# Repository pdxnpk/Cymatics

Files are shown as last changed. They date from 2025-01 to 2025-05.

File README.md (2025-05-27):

# Cymatics

Integrated PCBs for AudioLux and Vibrosonics

# Development

Install KiCad (version 8.0 or higher): https://www.kicad.org/download/

Open KiCad project file (Cymatics/Cymatics.kicad_pro)

# Build a PCB

## Order PCB

Go to JLCPCB (https://jlcpcb.com/) or PCBWay (https://www.pcbway.com/) to order a PCB

Start an order for a 2-layer PCB (Standard)

Add zip file of Gerber and Drill files (Fabrication/Cymatics_Gerber_Drill_03-21-25.zip)

Default specifications and options are OK

## Parts and Assembly

You may choose to have the PCB manufacturer assemble the boards for you, or you may order the parts separately and assemble the board on your own.

### Order PCB assembly

Provide the BOM and CPL (component placement list, or Centroid) for the manufacturer when requesting PCB assembly.

- Fabrication/Fabrication-BOM.xlsx: BOM adhering to PCBWay format (may need to revise for other manufacturers)

- Fabrication/Fabrication-CPL.csv: CPL or Centroid

### Order components separately

Open shopping list (Shopping-List.csv) to find links to order parts

Go to DigiKey (https://www.digikey.com/) and order listed part quanities

# Program the Microcontroller

To program the ESP32 with AudioLux and/or VibroSonics software, refer to their respective GitHub repositories.

- AudioLux software: https://github.com/OPEnSLab-OSU/Nanolux

- VibroSonics software: https://github.com/udellc/Vibrosonics

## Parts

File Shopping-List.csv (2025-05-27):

Reference | Footprint | Value | Order Link (Datasheet) | Qty | Price per unit |  | Notes
U1 | D14 | SN74AHCT125DR | https://www.digikey.com/en/products/detail/texas-instruments/SN74AHCT125DR/376412 | 1 | 0.26 | 0.26
J18 | TerminalBlock_TE-Connectivity:TerminalBlock_TE_282834-6_1x06_P2.54mm_Horizontal | Screw_Terminal_01x06 | https://www.digikey.com/en/products/detail/te-connectivity-amp-connectors/282834-6/1153267 | 1 | 8.84 | 8.84
J11 | TerminalBlock_TE-Connectivity:TerminalBlock_TE_282834-5_1x05_P2.54mm_Horizontal | Screw_Terminal_01x05 | https://www.digikey.com/en/products/detail/te-connectivity-amp-connectors/282834-5/1153266 | 1 | 6.2 | 6.2
J8,J10 | TerminalBlock_TE-Connectivity:TerminalBlock_TE_282834-4_1x04_P2.54mm_Horizontal | Screw_Terminal_01x04 | https://www.digikey.com/en/products/detail/te-connectivity-amp-connectors/282834-4/1153265 | 2 | 5.08 | 10.16
J1,J3,J4,J16 | TerminalBlock_TE-Connectivity:TerminalBlock_TE_282834-3_1x03_P2.54mm_Horizontal | Screw_Terminal_01x03 | https://www.digikey.com/en/products/detail/te-connectivity-amp-connectors/282834-3/1153264 | 4 | 3.93 | 15.72
J2,J5,J9,J12,J13,J15,J17 | TerminalBlock_TE-Connectivity:TerminalBlock_TE_282834-2_1x02_P2.54mm_Horizontal | Screw_Terminal_01x02 | https://www.digikey.com/en/products/detail/te-connectivity-amp-connectors/282834-2/1150135 | 7 | 2.74 | 19.18
J14,J19,J20,J21,J22,J23,J24 | CONN1_RCU-0C_TEC | RCU-0C | https://www.digikey.com/en/products/detail/te-connectivity-amp-connectors/RCU-0C/2366048 | 7 | 0.22 | 1.54
SD1 | MSD-4-A:CUI_MSD-4-A | MSD-4-A | https://www.digikey.com/en/products/detail/same-sky-formerly-cui-devices/MSD-4-A/21796808 | 1 | 0.36 | 0.36
U2 | 21-0041B_8_MXM | MAX7480ESA+ | https://www.digikey.com/en/products/detail/analog-devices-inc-maxim-integrated/max7480esa/1513397 | 1 | 9.24 | 9.24
IC2,IC5 | 21-0041B_8_MXM | MAX7403CSA+ | https://www.digikey.com/en/products/detail/analog-devices-inc-maxim-integrated/max7403csa/1513320 | 2 | 8.78 | 17.56
IC1,IC3,IC4 | D8 | LMV358IDR | https://www.digikey.com/en/products/detail/texas-instruments/LMV358IDR/381251 | 3 | 0.38 | 1.14
J6 | Connector_PinSocket_2.54mm:PinSocket_1x16_P2.54mm_Vertical | Conn_01x16_Socket | https://www.digikey.com/en/products/detail/sullins-connector-solutions/PPTC161LFBN-RC/810154 | 1 | 0.9 | 0.9
J7 | Connector_PinSocket_2.54mm:PinSocket_1x12_P2.54mm_Vertical | Conn_01x12_Socket | https://www.digikey.com/en/products/detail/sullins-connector-solutions/PPTC121LFBN-RC/807231 | 1 | 0.73 | 0.73
RN1,RN2 | CAY16-473:RESCAF80P320X160X60-8N | CAY16-473J4LF | https://www.digikey.com/en/products/detail/bourns-inc/CAY16-473J4LF/2566758 | 2 | 0.1 | 0.2
RN3 | CAY16-103:RESCAF80P320X160X60-8N | CAY16-103J4LF | https://www.digikey.com/en/products/detail/bourns-inc/CAY16-103J4LF/431579 | 1 | 0.1 | 0.1
R9,R22 | Resistor_SMD:R_1206_3216Metric | 22k | https://www.digikey.com/en/products/detail/yageo/RC1206FR-0722KL/728688 | 2 | 0.1 | 0.2
R1,R2,R3,R4,R7,R8,R12,R13,R16,R17,R20,R21,R24,R25 | Resistor_SMD:R_1206_3216Metric | 10k | https://www.digikey.com/en/products/detail/yageo/RC1206FR-0710KL/728483 | 14 | 0.1 | 1.4
R5 | Resistor_SMD:R_1206_3216Metric | 7.5k | https://www.digikey.com/en/products/detail/yageo/RC1206FR-077K5L/729079 | 1 | 0.1 | 0.1
R10,R23 | Resistor_SMD:R_1206_3216Metric | 6.2k | https://www.digikey.com/en/products/detail/yageo/RC1206FR-076K2L/729016 | 2 | 0.1 | 0.2
R6 | Resistor_SMD:R_1206_3216Metric | 5k | https://www.digikey.com/en/products/detail/yageo/RT1206BRD075KL/5936961 | 1 | 0.32 | 0.32
R19,R26 | Resistor_SMD:R_1206_3216Metric | 3.3k | https://www.digikey.com/en/products/detail/yageo/RC1206FR-073K3L/728766 | 2 | 0.1 | 0.2
R15,R18 | Resistor_SMD:R_1206_3216Metric | 1.5k | https://www.digikey.com/en/products/detail/yageo/RC1206FR-071K5L/728441 | 2 | 0.1 | 0.2
R11,R14 | Resistor_SMD:R_1206_3216Metric | 150 | https://www.digikey.com/en/products/detail/yageo/RC1206JR-07150RL/729223 | 2 | 0.1 | 0.2
C17 | Capacitor_THT:CP_Radial_D8.0mm_P5.00mm | 1000uF | https://www.digikey.com/en/products/detail/rubycon/10ZLH1000MEFC10X12-5/3134015 | 1 | 0.54 | 0.54
C1,C2,C6,C7,C8,C10,C11,C15,C20,C21,C22,C23 | Capacitor_SMD:C_0805_2012Metric | 10uF | https://www.digikey.com/en/products/detail/yageo/CC0805ZKY5V6BB106/2103093 | 12 | 0.15 | 1.8
C3,C4,C9,C12,C13,C16,C18,C24,C25 | Capacitor_SMD:C_0805_2012Metric | 0.1uF | https://www.digikey.com/en/products/detail/yageo/CC0805KRX7R9BB104/302874 | 9 | 0.08 | 0.72
C19 | Capacitor_SMD:C_0805_2012Metric | 6.8nF | https://www.digikey.com/en/products/detail/yageo/CC0805KRX7R9BB682/302869 | 1 | 0.1 | 0.1
C5,C14 | Capacitor_SMD:C_0805_2012Metric | 100pF | https://www.digikey.com/en/products/detail/yageo/CC0805JRNPO9BN101/302845 | 2 | 0.1 | 0.2
 |  |  |  |  |  | 98.31 | Total cost of 1 Cymatics PCB
External Modules | Part Number |  | Order Link (Datasheet)
Stereo Pot 1k linear | PDB182-K220K-102B |  | https://www.digikey.com/en/products/detail/bourns-inc/PDB182-K220K-102B/2564758 | 1 | 2.18 | 2.18
Rotary Encoder | PEC11R-4215F-S0024 |  | https://www.digikey.com/en/products/detail/bourns-inc/PEC11R-4215F-S0024/4499665 | 1 | 2.2 | 2.2
Stereo Jack 3.5mm | 35PRM3 |  | https://www.digikey.com/en/products/detail/switchcraft-inc/35PRM3/6695851 | 1 | 2.16 | 2.16
Buck Converter | DFR1015 |  | https://www.digikey.com/en/products/detail/dfrobot/DFR1015/18069278 | 1 | 5.3 | 5.3
Red LED | C503B-RAN-CA0B0AA1 |  | https://www.digikey.com/en/products/detail/cree-led/C503B-RAN-CA0B0AA1/4793651 | 2 | 0.22 | 0.44
Pololu LED Strip | SK9822 |  | https://www.pololu.com/product/3086 | 1 | 25.7 | 25.7
Adafruit Amplifier Board | MAX9744 |  | https://www.adafruit.com/product/1752 | 1 | 19.95 | 19.95
Dayton Audio Transducer | TT25-8 |  | https://www.amazon.com/Dayton-Audio-TT25-8-Tactile-Transducer/dp/B009RGJ47S/ref=sr_1_1_pp?sr=8-1 | 3 | 17.34 | 52.02
 |  |  |  |  |  | 109.95 | Total cost of external modules for 1 system
 |  |  |  |  |  | 208.26 | Total cost of 1 system (PCB and external modules). May vary due to bulk pricing and shipping fees .

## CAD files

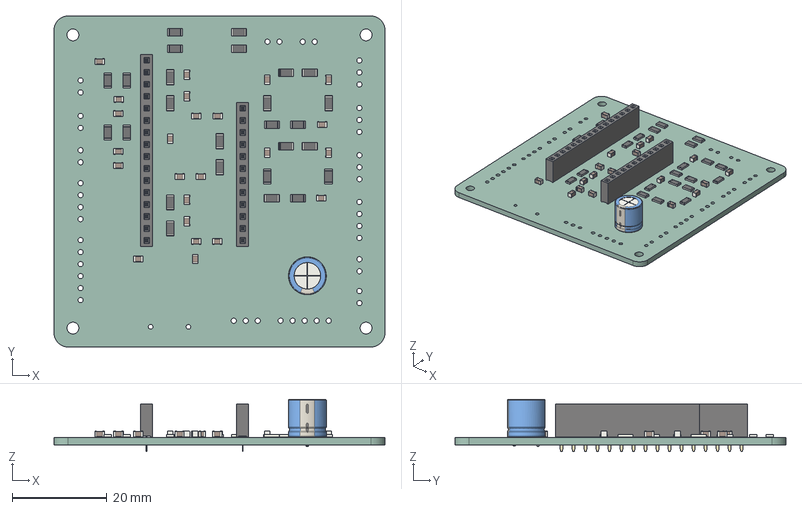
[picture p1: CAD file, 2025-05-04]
Cymatics/Cymatics.step
70.0 x 70.0 x 11.1 mm
R_1206_3216Metric x 26
C_0805_2012Metric x 24
PinSocket_1x12_P254mm_Vertical
CP_Radial_D80mm_P500mm
PinSocket_1x16_P254mm_Vertical
Cymatics_PCB

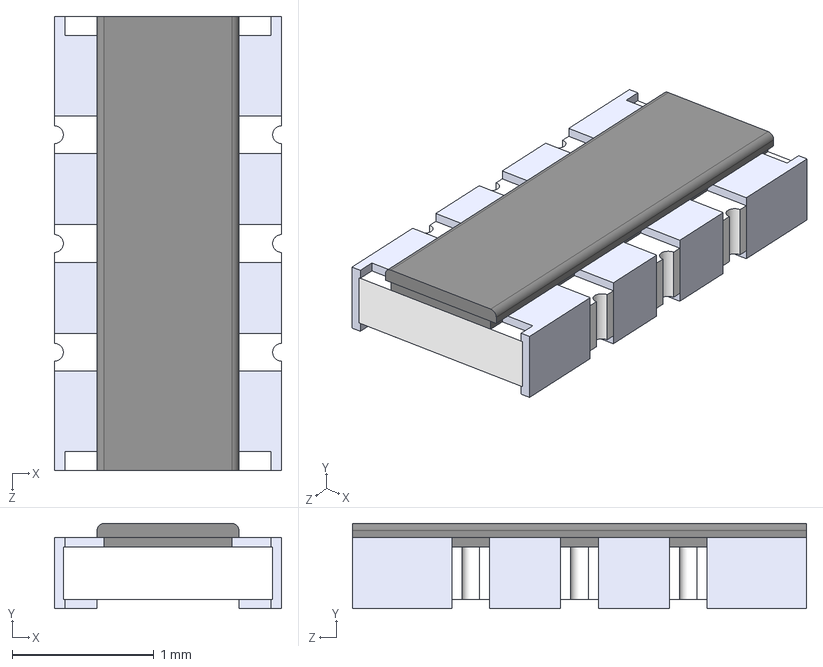
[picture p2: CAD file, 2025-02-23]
Cymatics/Footprints/CAY16_103J4LF/CAY16-103J4LF.step
1.60 x 0.6 x 3.20 mm

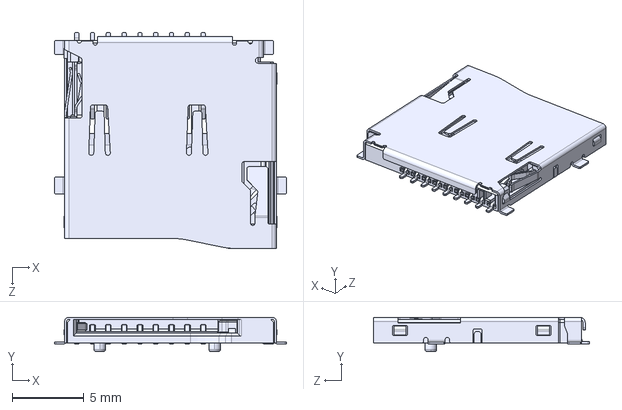
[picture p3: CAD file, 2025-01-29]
Cymatics/Footprints/MSD_4_A/MSD-4-A.step
16.1 x 2.40 x 15.0 mm

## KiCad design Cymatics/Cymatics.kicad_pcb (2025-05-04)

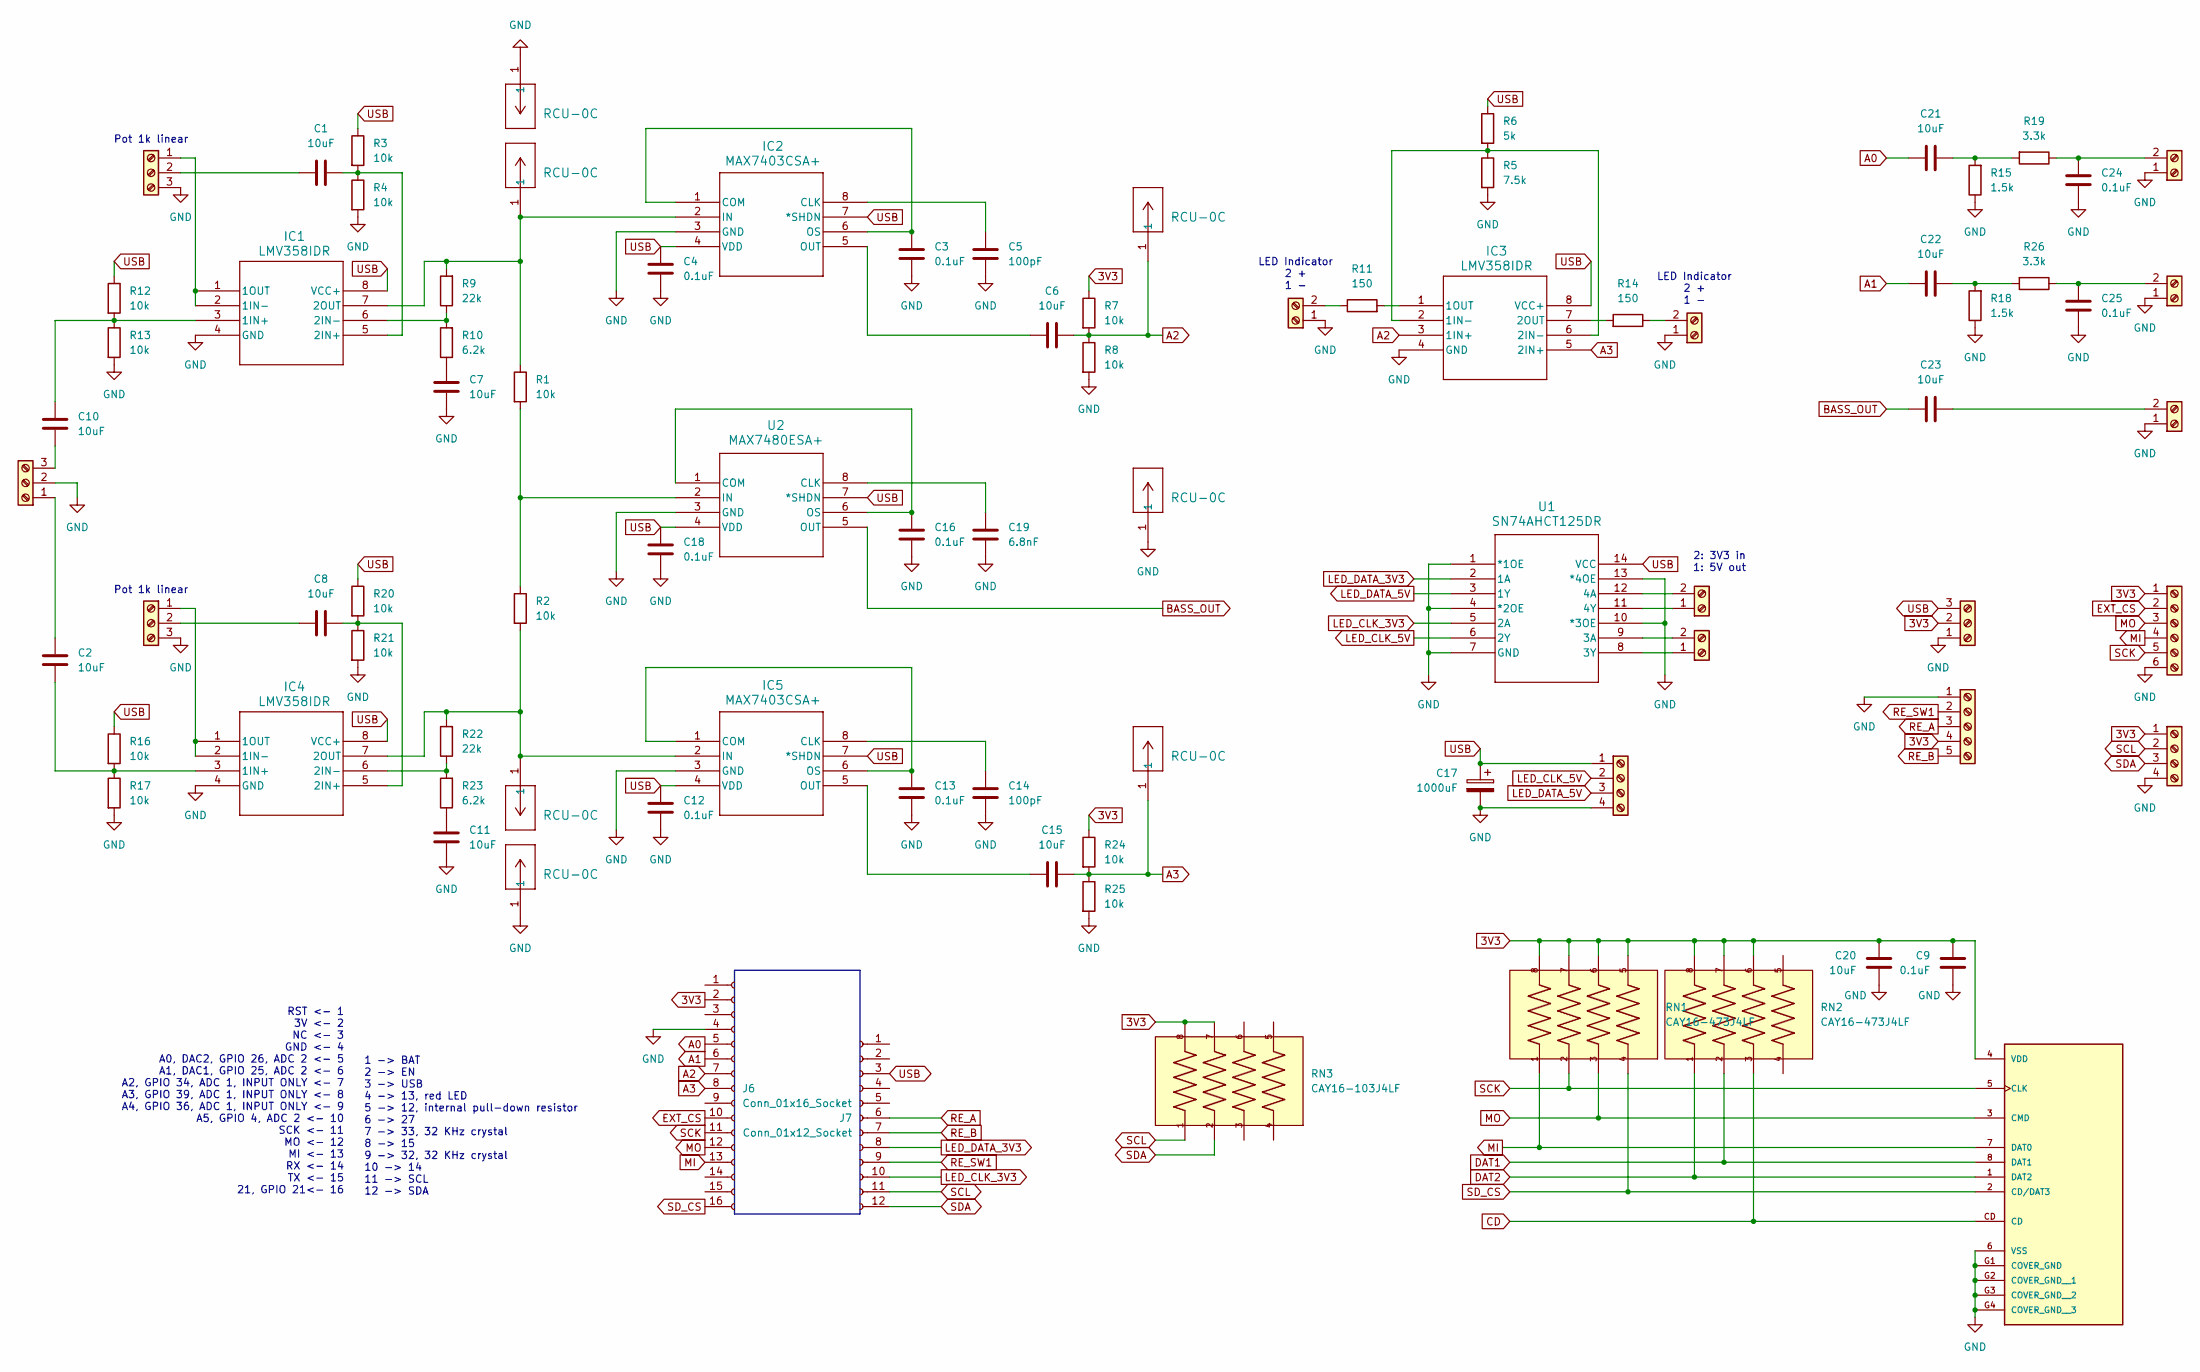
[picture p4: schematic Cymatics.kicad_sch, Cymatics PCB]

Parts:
C1, C2, C6, C7, C8, C10, C11, C15, C20, C21, C22, C23: 10uF; C_0805_2012Metric
C3, C4, C9, C12, C13, C16, C18, C24, C25: 0.1uF; C_0805_2012Metric
C5, C14: 100pF; C_0805_2012Metric
C17: 1000uF; CP_Radial_D8.0mm_P5.00mm
C19: 6.8nF; C_0805_2012Metric
IC1, IC3, IC4: LMV358IDR; D8
IC2, IC5: MAX7403CSA+; 21-0041B_8_MXM
J1, J3, J4, J16: Screw_Terminal_01x03; TerminalBlock_TE_282834-3_1x03_P2.54mm_Horizontal
J2, J5, J9, J12, J13, J15, J17: Screw_Terminal_01x02; TerminalBlock_TE_282834-2_1x02_P2.54mm_Horizontal
J6: Conn_01x16_Socket; PinSocket_1x16_P2.54mm_Vertical
J7: Conn_01x12_Socket; PinSocket_1x12_P2.54mm_Vertical
J8, J10: Screw_Terminal_01x04; TerminalBlock_TE_282834-4_1x04_P2.54mm_Horizontal
J11: Screw_Terminal_01x05; TerminalBlock_TE_282834-5_1x05_P2.54mm_Horizontal
J14, J19, J20, J21, J22, J23, J24: RCU-0C; CONN1_RCU-0C_TEC
J18: Screw_Terminal_01x06; TerminalBlock_TE_282834-6_1x06_P2.54mm_Horizontal
R1, R2, R3, R4, R7, R8, R12, R13, R16, R17, R20, R21, R24, R25: 10k; R_1206_3216Metric
R5: 7.5k; R_1206_3216Metric
R6: 5k; R_1206_3216Metric
R9, R22: 22k; R_1206_3216Metric
R10, R23: 6.2k; R_1206_3216Metric
R11, R14: 150; R_1206_3216Metric
R15, R18: 1.5k; R_1206_3216Metric
R19, R26: 3.3k; R_1206_3216Metric
RN1, RN2: CAY16-473J4LF; RESCAF80P320X160X60-8N
RN3: CAY16-103J4LF; RESCAF80P320X160X60-8N
SD1: MSD-4-A; CUI_MSD-4-A; PARTREV 1.0
U1: SN74AHCT125DR; D14
U2: MAX7480ESA+; 21-0041B_8_MXM

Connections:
3V3: C9.2, C20.1, J1.2, J6.2, J8.1, J11.4, J18.1, R7.1, R24.1, RN1.5, RN1.6, RN1.7, RN1.8, RN2.6, RN2.7, RN2.8, RN3.7, RN3.8, SD1.4 (VDD)
A0: C21.2, J6.5
A1: C22.2, J6.6
A2: C6.1, IC3.3 (1IN+), J6.7, J22.1, R7.2, R8.1
A3: C15.1, IC3.5 (2IN+), J6.8, J23.1, R24.2, R25.1
BASS_OUT: C23.2, U2.5 (OUT)
CD: RN2.3, SD1.CD
DAT1: RN2.2, SD1.8 (DAT1)
DAT2: RN2.1, SD1.1 (DAT2)
EXT_CS: J6.10, J18.2
GND: C3.1, C4.1, C5.1, C7.1, C9.1, C11.1, C12.1, C13.1, C14.1, C16.1, C17.2, C18.1, C19.1, C20.2, C24.1, C25.1, IC1.4 (GND), IC2.3 (GND), IC3.4 (GND), IC4.4 (GND), IC5.3 (GND), J1.1, J3.2, J4.3, J5.1, J6.4, J8.4, J10.4, J11.1, J12.1, J13.1, J15.1, J16.3, J17.1, J18.6, J19.1, J21.1, J24.1, R4.2, R5.2, R8.2, R13.2, R15.1, R17.2, R18.1, R21.2, R25.2, SD1.6 (VSS), SD1.G1 (COVER_GND), SD1.G2 (COVER_GND__1), SD1.G3 (COVER_GND__2), SD1.G4 (COVER_GND__3), U1.1 (*1OE), U1.4 (*2OE), U1.7 (GND), U1.10 (*3OE), U1.13 (*4OE), U2.3 (GND)
LED_CLK_3V3: J7.10, U1.5 (2A)
LED_CLK_5V: J10.2, U1.6 (2Y)
LED_DATA_3V3: J7.8, U1.2 (1A)
LED_DATA_5V: J10.3, U1.3 (1Y)
MI: J6.13, J18.4, RN1.1, SD1.7 (DAT0)
MO: J6.12, J18.3, RN1.3, SD1.3 (CMD)
unnamed: C7.2, R10.1
unnamed: C11.2, R23.1
unnamed: C21.1, R15.2, R19.2
unnamed: C22.1, R18.2, R26.2
unnamed: C10.1, IC1.3 (1IN+), R12.2, R13.1
unnamed: IC1.1 (1OUT), IC1.2 (1IN-), J4.1
unnamed: C1.1, IC1.5 (2IN+), R3.2, R4.1
unnamed: IC1.6 (2IN-), R9.1, R10.2
unnamed: IC1.7 (2OUT), IC2.2 (IN), J14.1, R1.1, R9.2
unnamed: C5.2, IC2.8 (CLK)
unnamed: C3.2, IC2.1 (COM), IC2.6 (OS)
unnamed: C6.2, IC2.5 (OUT)
unnamed: IC3.2 (1IN-), IC3.6 (2IN-), R5.1, R6.2
unnamed: IC3.1 (1OUT), R11.2
unnamed: IC3.7 (2OUT), R14.2
unnamed: C2.2, IC4.3 (1IN+), R16.2, R17.1
unnamed: IC4.1 (1OUT), IC4.2 (1IN-), J16.1
unnamed: C8.1, IC4.5 (2IN+), R20.2, R21.1
unnamed: IC4.6 (2IN-), R22.1, R23.2
unnamed: IC4.7 (2OUT), IC5.2 (IN), J20.1, R2.2, R22.2
unnamed: C14.2, IC5.8 (CLK)
unnamed: C13.2, IC5.1 (COM), IC5.6 (OS)
unnamed: C15.2, IC5.5 (OUT)
unnamed: J2.1, U1.11 (4Y)
unnamed: J2.2, U1.12 (4A)
unnamed: C2.1, J3.1
unnamed: C10.2, J3.3
unnamed: C1.2, J4.2
unnamed: J5.2, R11.1
unnamed: J9.1, U1.8 (3Y)
unnamed: J9.2, U1.9 (3A)
unnamed: C24.2, J12.2, R19.1
unnamed: C25.2, J13.2, R26.1
unnamed: J15.2, R14.1
unnamed: C8.2, J16.2
unnamed: C23.1, J17.2
unnamed: C19.2, U2.8 (CLK)
unnamed: C16.2, U2.1 (COM), U2.6 (OS)
unnamed: R1.2, R2.1, U2.2 (IN)
RE_A: J7.6, J11.3
RE_B: J7.7, J11.5
RE_SW1: J7.9, J11.2
SCK: J6.11, J18.5, RN1.2, SD1.5 (CLK)
SCL: J7.11, J8.2, RN3.1
SDA: J7.12, J8.3, RN3.2
SD_CS: J6.16, RN1.4, SD1.2 (CD/DAT3)
USB: C4.2, C12.2, C17.1, C18.2, IC1.8 (VCC+), IC2.4 (VDD), IC2.7 (*SHDN), IC3.8 (VCC+), IC4.8 (VCC+), IC5.4 (VDD), IC5.7 (*SHDN), J1.3, J7.3, J10.1, R3.1, R6.1, R12.1, R16.1, R20.1, U1.14 (VCC), U2.4 (VDD), U2.7 (*SHDN)

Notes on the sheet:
LED Indicator 2 + 1 -
Pot 1k linear
RST <- 1 3V <- 2 NC <- 3 GND <- 4 A0, DAC2, GPIO 26, ADC 2 <- 5 A1, DAC1, GPIO 25, ADC 2 <- 6 A2, GPIO 34, ADC 1, INPUT ONLY <- 7 A3, GPIO 39, ADC 1, INPUT ONLY <- 8 A4, GPIO 36, ADC 1, INPUT ONLY <- 9 A5, GPIO 4, ADC 2 <- 10 SCK <- 11 MO <- 12 MI <- 13 RX <- 14 TX <- 15 21, GPIO 21<- 16
1 -> BAT 2 -> EN 3 -> USB 4 -> 13, red LED 5 -> 12, internal pull-down resistor 6 -> 27 7 -> 33, 32 KHz crystal 8 -> 15 9 -> 32, 32 KHz crystal 10 -> 14 11 -> SCL 12 -> SDA
2: 3V3 in 1: 5V out

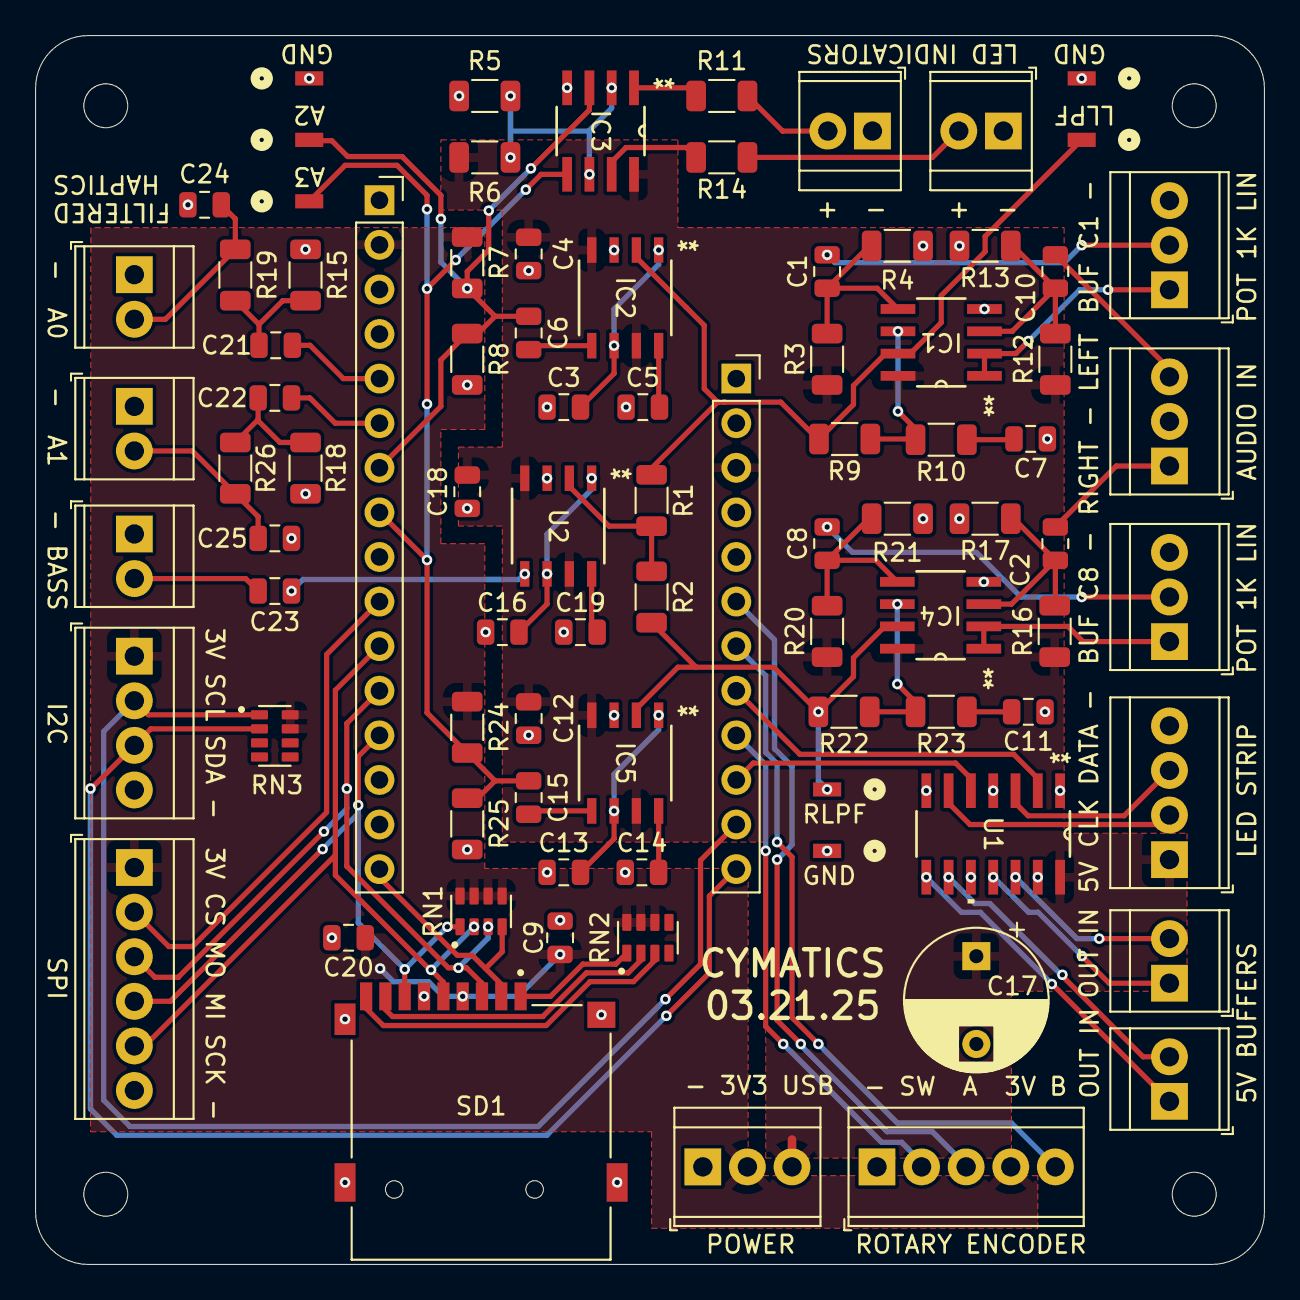
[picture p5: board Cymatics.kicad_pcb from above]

Board: 2 copper layers, 70.0 x 70.0 mm, 86 parts (0 on the bottom side), 64 nets.

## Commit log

2025-01-29 Copy AudioLux and Cymatics into repo
    [AudioLux-B_Cu.gbl, AudioLux-B_Mask.gbs, AudioLux-B_Paste.gbp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]
2025-01-29 rel paths for AudioLux footprints/symbols library
    [AudioLux.kicad_pcb]
2025-01-29 resolved all DRC errors
    [Cymatics.kicad_pcb, Cymatics.kicad_sch]
2025-01-31 added testpoints
    [Cymatics.kicad_pcb, Cymatics.kicad_sch]
2025-01-31 testpoints update and terminal block labels
    [Cymatics.kicad_pcb, Cymatics.kicad_sch]
2025-02-01 swizzled rotary encoder block
    [Cymatics.kicad_pcb, Cymatics.kicad_sch]
2025-02-02 new testpoint RCU-0C
    [Cymatics.kicad_pcb, Cymatics.kicad_sch]
2025-02-02 changes and Gerber Drill generate for order
    [Cymatics-B_Cu.gbl, Cymatics-B_Mask.gbs, Cymatics-B_Paste.gbp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]
2025-02-02 added cymatics label and ordered PCB and parts
    [Cymatics-B_Cu.gbl, Cymatics-B_Mask.gbs, Cymatics-B_Paste.gbp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]
2025-02-22 changed positioning of blocks for diagrams
    [Cymatics.kicad_pcb, Cymatics.kicad_sch]
2025-02-23 pull up resistors for SPI and I2C
    [CAY16-473J4LF.step, Cymatics.kicad_pcb, Cymatics.kicad_sch]
2025-02-26 use 10k pullup for I2C and DAT1/2
    [CAY16-103J4LF.step, Cymatics.kicad_pcb, Cymatics.kicad_sch]
2025-02-27 Order for March PCB
    [Cymatics-B_Cu.gbl, Cymatics-B_Mask.gbs, Cymatics-B_Paste.gbp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]
2025-03-12 All changes up through Week 9, including making the step file
    [Cymatics-B_Cu.gbl, Cymatics-B_Mask.gbs, Cymatics-B_Paste.gbp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]
2025-03-12 added passive DAC filters to schem and layout
    [Cymatics.kicad_pcb, Cymatics.kicad_sch]
2025-05-04 misc updates
    [Cymatics-B_Cu.gbl, Cymatics-B_Mask.gbs, Cymatics-B_Paste.gbp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]
2025-05-18 bom and gerber zip
    [BOM.csv]
2025-05-24 fab folder
    [Fabrication-BOM.csv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]
2025-05-26 xlsx BOM for PCBWay
    [Fabrication-BOM.csv, Fabrication-BOM.xlsx]
2025-05-27 add shopping list
    [BOM.csv, Shopping-List.csv]
